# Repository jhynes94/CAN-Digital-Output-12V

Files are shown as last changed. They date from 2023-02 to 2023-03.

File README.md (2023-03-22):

# CAN-Digital-Output-12V
CAN controlled Digital Outputs providing 12V power with __ Current each.

## Items to complete
1. Detemine MOSFET to use for design (based on Current(A)/Costs constraints).
2. Design better interface board to use Arduino Nano Programmer
    1. JST Connector to Arduino Development Board
    2. 2.54mm Connector with standard interface board
    3. Consider adding UART connector as well.
3. Determine modes needed for device
    1. CAN ID changing?
    2. CAN Mode changing?
    3. How this should be modified? (DIP swich or via SW)

## Development Setup

Programming the ATTiny is a bit difficult. Setup can be completed using the following tutorial:
https://youtu.be/AL9vK_xMt4E

The library used for SPI enabled CAN device:
https://github.com/autowp/arduino-mcp2515

PEAK CAN usb device is used for interfacing and development. The software to run this is called <b>pcanview<b>

## Far Future items

Future Tutorial for programming an alternative way:
https://www.youtube.com/watch?v=ra7bT74EGUs

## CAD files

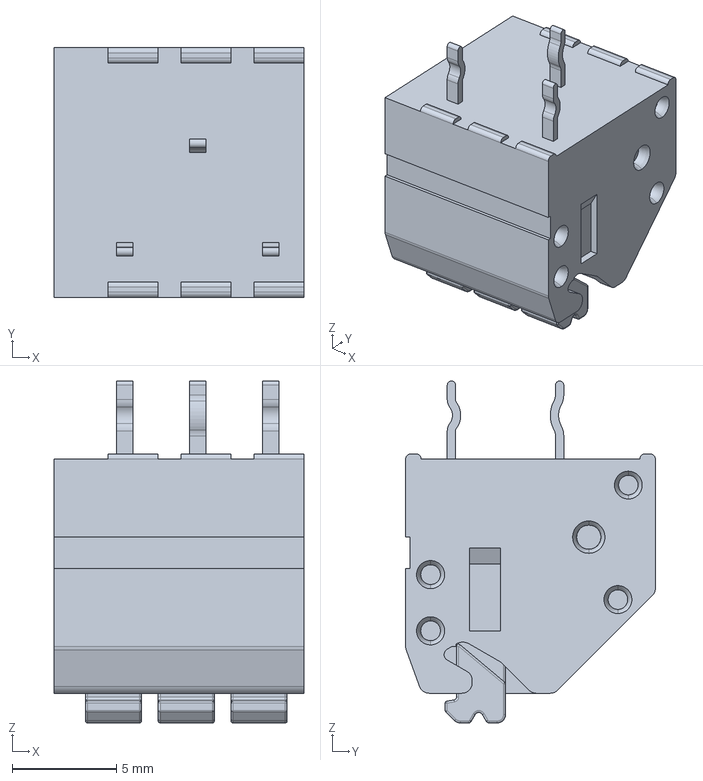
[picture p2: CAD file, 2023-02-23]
KICAD/Custom Components/1-2834011-3/1-2834011-3.step
12.0 x 12.0 x 16.4 mm

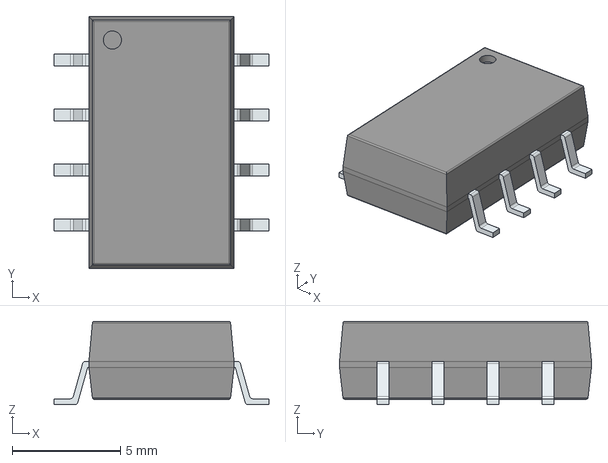
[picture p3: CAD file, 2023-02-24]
KICAD/Custom Components/219-4MSTR/219-4MSTR.stp
9.91 x 11.6 x 3.85 mm
PinsArrayLR

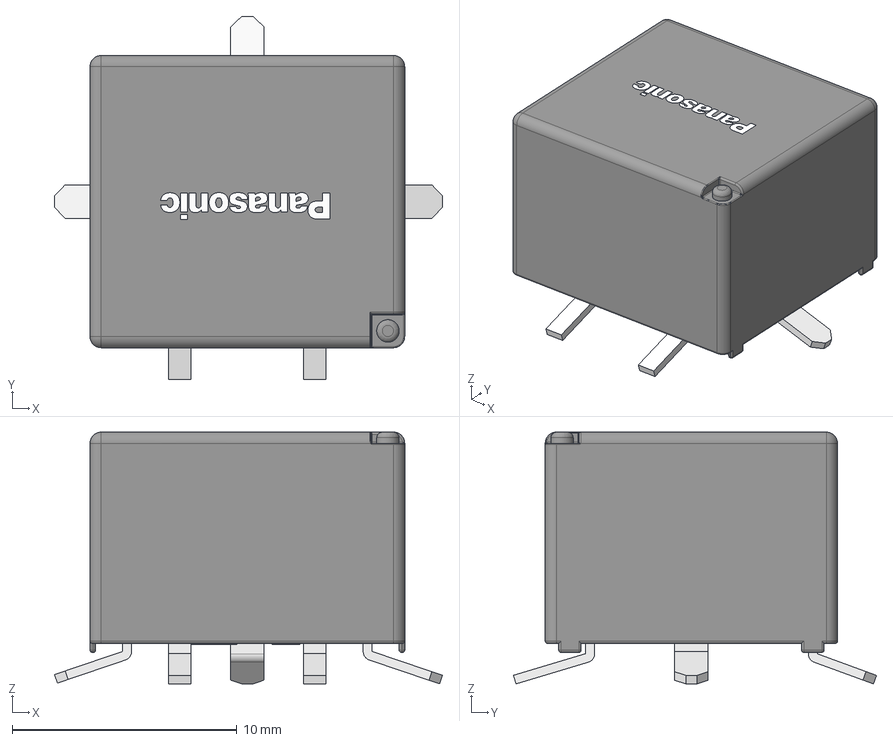
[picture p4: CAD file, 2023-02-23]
KICAD/Custom Components/eec.models/Panasonic_-_CP1SA-12V-X.step
17.3 x 16.2 x 11.2 mm
Relay
Leads
ring
Japan
Panasonic

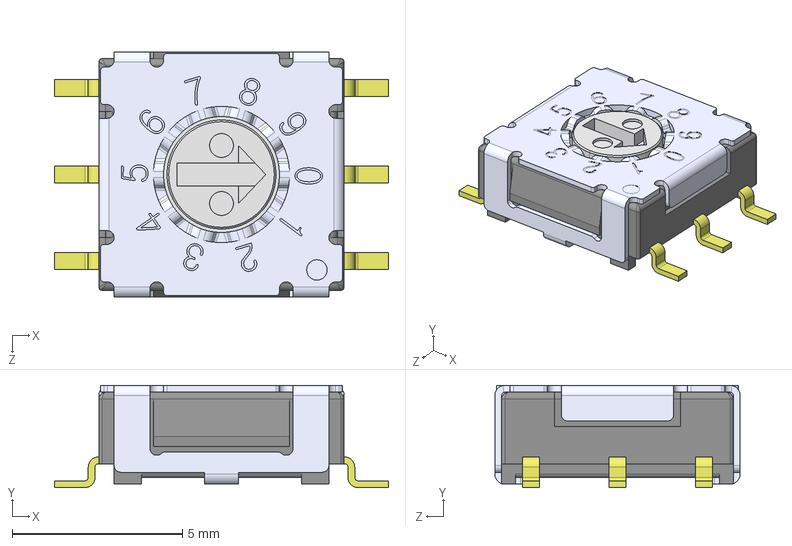
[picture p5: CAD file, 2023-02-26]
KICAD/Custom Components/RDS-10S-7229-A-SMT/CUI_DEVICES_RDS-10S-7229-A-SMT.step
9.80 x 3.00 x 7.20 mm
RDS-7229-SMT housing
RDS-7229_10_face plate
RDS-7229_flat arrow(10S)

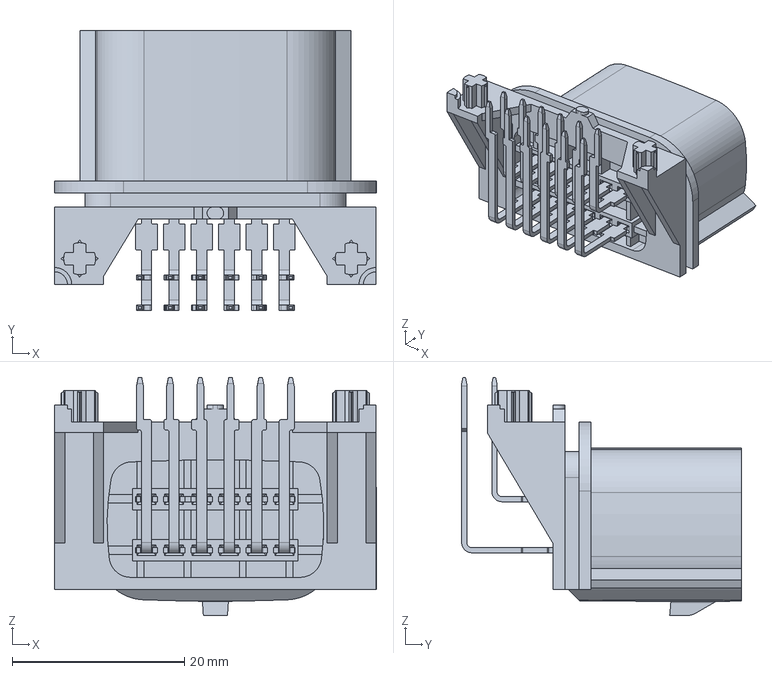
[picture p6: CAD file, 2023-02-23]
KICAD/Custom Components/0367831201/36783-1201.stp
37.4 x 32.5 x 27.6 mm

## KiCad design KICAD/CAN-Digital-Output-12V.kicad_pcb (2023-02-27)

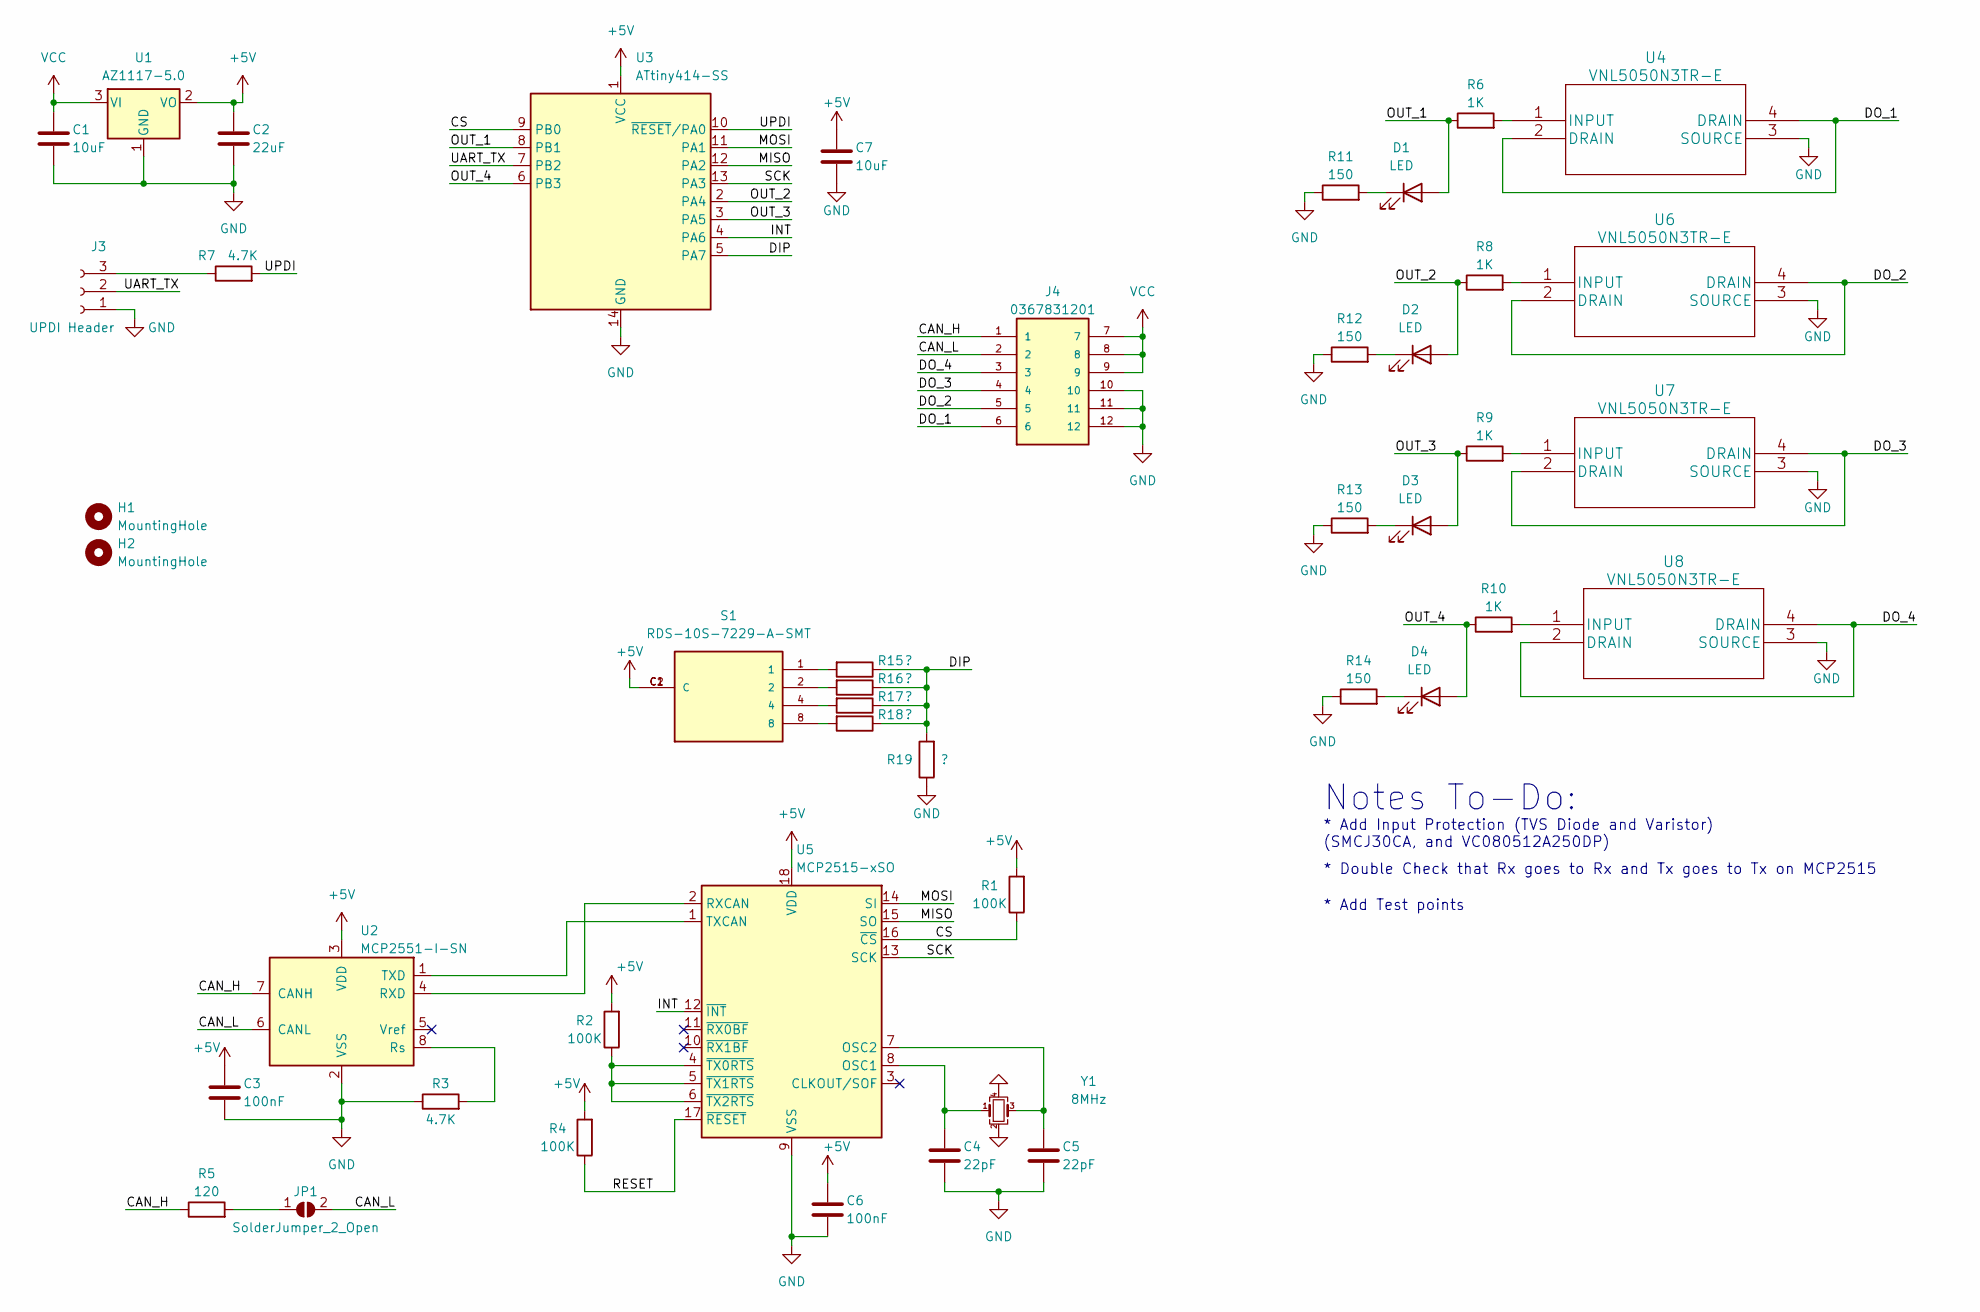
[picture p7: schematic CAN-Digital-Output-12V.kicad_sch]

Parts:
C1, C7: 10uF; C_0805_2012Metric_Pad1.18x1.45mm_HandSolder; Manufacturer PN CL21A106KOQNNNE; Digi-Key PN 1276-1096-2-ND
C2: 22uF; C_0805_2012Metric_Pad1.18x1.45mm_HandSolder; Manufacturer PN CL21A226MOCLRNC; Digi-Key PN 1276-6780-1-ND
C3, C6: 100nF; C_0603_1608Metric_Pad1.08x0.95mm_HandSolder; Manufacturer PN CL10B104KB8NNNC; Digi-Key PN 1276-1000-1-ND
C4, C5: 22pF; C_0603_1608Metric_Pad1.08x0.95mm_HandSolder; Manufacturer PN CC0603JRNPO9BN220; Digi-Key PN 311-1062-1-ND
D1, D2, D3, D4: LED; LED_0603_1608Metric_Pad1.05x0.95mm_HandSolder; Manufacturer PN LTST-C191KGKT; Digi-Key PN 160-1446-1-ND
H1, H2: MountingHole; MountingHole_2.2mm_M2_ISO14580
J3: UPDI Header; PinHeader_1x03_P1.27mm_Vertical
J4: 0367831201; MOLEX_0367831201; PARTREV F1; Digi-Key PN WM9330-ND
JP1: SolderJumper_2_Open; SolderJumper-2_P1.3mm_Open_TrianglePad1.0x1.5mm
R1, R2, R4: 100K; R_0603_1608Metric_Pad0.98x0.95mm_HandSolder; Manufacturer PN RC0603FR-07100KL; Digi-Key PN 311-100KHRCT-ND
R3, R7: 4.7K; R_0603_1608Metric_Pad0.98x0.95mm_HandSolder; Manufacturer PN RC0402JR-074K7L; Digi-Key PN 311-4.7KJRCT-ND
R5: 120; R_1206_3216Metric_Pad1.30x1.75mm_HandSolder; Manufacturer PN AC1206FR-07120RL; Digi-Key PN YAG3810CT-ND
R6, R8, R9, R10: 1K; R_0603_1608Metric_Pad0.98x0.95mm_HandSolder; Manufacturer PN RC0603FR-071KL; Digi-Key PN 311-1.00KHRCT-ND
R11, R12, R13, R14: 150; R_0603_1608Metric_Pad0.98x0.95mm_HandSolder; Manufacturer PN RC0603FR-07150RL; Digi-Key PN 311-150HRCT-ND
R15, R16, R17, R18, R19: ?; R_0603_1608Metric_Pad0.98x0.95mm_HandSolder
S1: RDS-10S-7229-A-SMT; SW_RDS-10S-7229-A-SMT; PARTREV 1.0; Digi-Key PN 2223-RDS-10S-7229-A-SMT-ND
U1: AZ1117-5.0; SOT-223-3_TabPin2; Manufacturer PN AZ1117IH-5.0TRG1; Digi-Key PN AZ1117IH-5.0TRG1DICT-ND
U2: MCP2551-I-SN; SOIC-8_3.9x4.9mm_P1.27mm; Manufacturer PN MCP2551-I/SN; Digi-Key PN MCP2551-I/SN-ND
U3: ATtiny414-SS; SOIC-14_3.9x8.7mm_P1.27mm; Manufacturer PN ATTINY414-SSNR; Digi-Key PN ATTINY414-SSNRCT-ND
U4, U6, U7, U8: VNL5050N3TR-E; SOT-223; Manufacturer PN VNL5050N3TR-E; Digi-Key PN 497-11709-1-ND
U5: MCP2515-xSO; SOIC-18W_7.5x11.6mm_P1.27mm; Manufacturer PN MCP2515-I/SO; Digi-Key PN MCP2515-I/SO-ND
Y1: 8MHz; Crystal_SMD_3225-4Pin_3.2x2.5mm_HandSoldering; Manufacturer PN ECS-80-8-33-JEN-TR3; Digi-Key PN 50-ECS-80-8-33-JEN-TR3CT-ND

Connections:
+5V: C2.1, C3.1, C6.1, C7.1, R1.2, R2.2, R4.2, S1.C1 (C), S1.C2 (C), U1.2 (VO), U2.3 (VDD), U3.1 (VCC), U5.18 (VDD)
/CAN_H: J4.1, R5.1, U2.7 (CANH)
/CAN_L: J4.2, JP1.2 (B), U2.6 (CANL)
/CS: R1.1, U3.9 (PB0), U5.16 (~CS)
/DIP: R15.1, R16.1, R17.1, R18.1, R19.2, U3.5 (PA7)
/DO_1: J4.6, U4.2 (DRAIN), U4.4 (DRAIN)
/DO_2: J4.5, U6.2 (DRAIN), U6.4 (DRAIN)
/DO_3: J4.4, U7.2 (DRAIN), U7.4 (DRAIN)
/DO_4: J4.3, U8.2 (DRAIN), U8.4 (DRAIN)
/INT: U3.4 (PA6), U5.12 (~INT)
/MISO: U3.12 (PA2), U5.15 (SO)
/MOSI: U3.11 (PA1), U5.14 (SI)
/OUT_1: D1.2 (A), R6.1, U3.8 (PB1)
/OUT_2: D2.2 (A), R8.1, U3.2 (PA4)
/OUT_3: D3.2 (A), R9.1, U3.3 (PA5)
/OUT_4: D4.2 (A), R10.1, U3.6 (PB3)
/RESET: R4.1, U5.17 (~RESET)
/SCK: U3.13 (PA3), U5.13 (SCK)
/UART_TX: J3.2, U3.7 (PB2)
/UPDI: R7.2, U3.10 (~RESET/PA0)
GND: C1.2, C2.2, C3.2, C4.2, C5.2, C6.2, C7.2, J3.1, J4.10, J4.11, J4.12, R3.1, R11.1, R12.1, R13.1, R14.1, R19.1, U1.1 (GND), U2.2 (VSS), U3.14 (GND), U4.3 (SOURCE), U5.9 (VSS), U6.3 (SOURCE), U7.3 (SOURCE), U8.3 (SOURCE), Y1.2, Y1.4
unnamed: C4.1, U5.8 (OSC1), Y1.1
unnamed: C5.1, U5.7 (OSC2), Y1.3
unnamed: D1.1 (K), R11.2
unnamed: D2.1 (K), R12.2
unnamed: D3.1 (K), R13.2
unnamed: D4.1 (K), R14.2
unnamed: J3.3, R7.1
unnamed: JP1.1 (A), R5.2
unnamed: R2.1, U5.4 (~TX0RTS), U5.5 (~TX1RTS), U5.6 (~TX2RTS)
unnamed: R3.2, U2.8 (Rs)
unnamed: R6.2, U4.1 (INPUT)
unnamed: R8.2, U6.1 (INPUT)
unnamed: R9.2, U7.1 (INPUT)
unnamed: R10.2, U8.1 (INPUT)
unnamed: R15.2, S1.1
unnamed: R16.2, S1.2
unnamed: R17.2, S1.4
unnamed: R18.2, S1.8
unnamed: U2.1 (TXD), U5.1 (TXCAN)
unnamed: U2.4 (RXD), U5.2 (RXCAN)
VCC: C1.1, J4.7, J4.8, J4.9, U1.3 (VI)

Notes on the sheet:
* Add Input Protection (TVS Diode and Varistor) (SMCJ30CA, and VC080512A250DP)
* Double Check that Rx goes to Rx and Tx goes to Tx on MCP2515
Notes To-Do:
* Add Test points

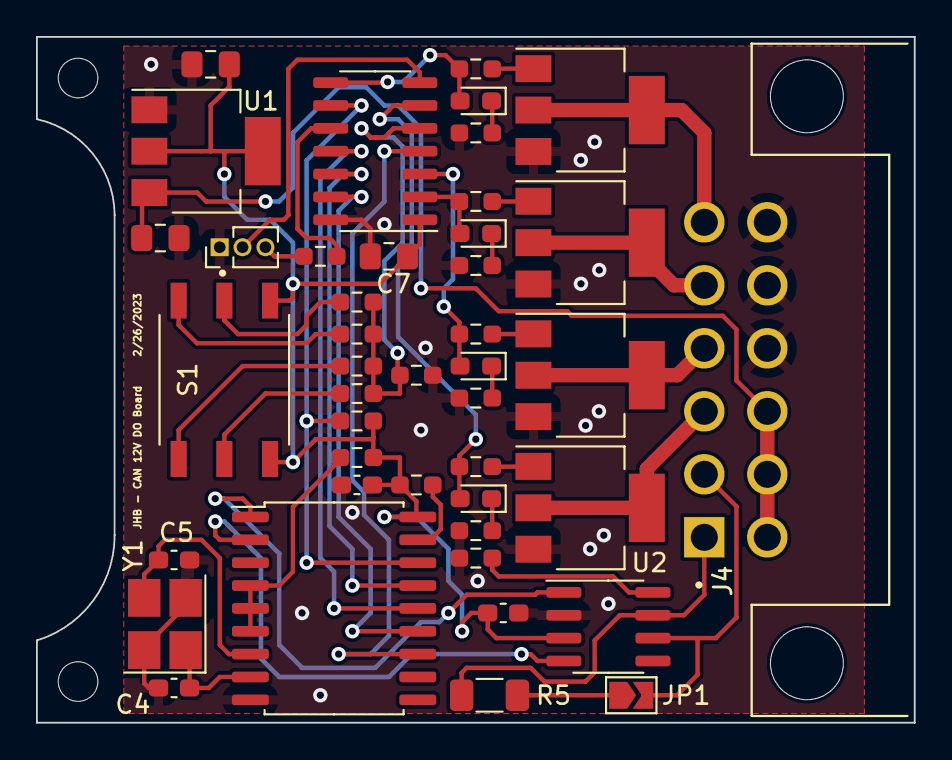
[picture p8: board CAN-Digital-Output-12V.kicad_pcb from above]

Board: 2 copper layers, 48.8 x 38.1 mm, 45 parts (0 on the bottom side), 42 nets.

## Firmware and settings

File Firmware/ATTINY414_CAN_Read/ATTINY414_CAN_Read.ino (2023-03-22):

#include <SPI.h>
#include <mcp2515.h>

#define OUT_1 6
#define OUT_2 0
#define OUT_3 1
#define OUT_4 4

bool blink_Out_1 = false
bool blink_Out_2 = false
bool blink_Out_3 = false
bool blink_Out_4 = false

struct can_frame canMsg;
MCP2515 mcp2515(7);

unsigned int device_CAN_ID = 1;

void setup() {
  
  mcp2515.reset();
  mcp2515.setBitrate(CAN_125KBPS, MCP_8MHZ);
  mcp2515.setNormalMode();

  //Setup Digital Outputs
  pinMode(OUT_1, OUTPUT);
  pinMode(OUT_2, OUTPUT);
  pinMode(OUT_3, OUTPUT);
  pinMode(OUT_4, OUTPUT);
}

void loop() {

  if (mcp2515.readMessage(&canMsg) == MCP2515::ERROR_OK) {
      
    //If it is the correct CAN ID
    if(canMsg.can_id == device_CAN_ID){
      
      unsigned int mask = 0b00000010;
      if((canMsg.data[0]&mask) != 0){
        digitalWrite(OUT_1, HIGH);
      }
      else {
        digitalWrite(OUT_1, LOW);
      }
      
      /*
      //Iterates Through Data    
      for (int i = 0; i<canMsg.can_dlc; i++) {
        //canMsg.data[i],HEX);
      }
      */
    }
  }
}

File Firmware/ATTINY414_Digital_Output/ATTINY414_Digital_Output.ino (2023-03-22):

#include <SPI.h>
#include <mcp2515.h>

#define OUT_1 6
#define OUT_2 0
#define OUT_3 1
#define OUT_4 4

bool blink_Out_1 = false;
bool blink_Out_2 = false;
bool blink_Out_3 = false;
bool blink_Out_4 = false;

struct can_frame canMsg;
MCP2515 mcp2515(7);

unsigned int device_CAN_ID = 1;

unsigned long currentMillis;
unsigned long previousMillis = 0;
const unsigned long interval = 1000;
int ledState = LOW;

void setup() {
  
  mcp2515.reset();
  mcp2515.setBitrate(CAN_125KBPS, MCP_8MHZ);
  mcp2515.setNormalMode();

  //Setup Digital Outputs
  pinMode(OUT_1, OUTPUT);
  pinMode(OUT_2, OUTPUT);
  pinMode(OUT_3, OUTPUT);
  pinMode(OUT_4, OUTPUT);
}

void loop() {

  if (mcp2515.readMessage(&canMsg) == MCP2515::ERROR_OK) {
      
    //If it is the correct CAN ID
    if(canMsg.can_id == device_CAN_ID){
      
      if(canMsg.data[0] > 0){
        digitalWrite(OUT_1, HIGH);
        blink_Out_1 = false;
        if(canMsg.data[0] > 10){
          blink_Out_1 = true;
        } 
      }
      else {
        digitalWrite(OUT_1, LOW);
        blink_Out_1 = false;
      }


      if(canMsg.data[1] > 0){
        digitalWrite(OUT_2, HIGH);
        blink_Out_2 = false;
        if(canMsg.data[1] > 10){
          blink_Out_2 = true;
        }
      }
      else {
        digitalWrite(OUT_2, LOW);
        blink_Out_2 = false;
      }

      if(canMsg.data[2] > 0){
        digitalWrite(OUT_3, HIGH);
        blink_Out_3 = false;
        if(canMsg.data[2] > 10){
          blink_Out_3 = true;
        }
      }
      else {
        digitalWrite(OUT_3, LOW);
        blink_Out_3 = false;
      }
      
      if(canMsg.data[3] > 0){
        digitalWrite(OUT_4, HIGH);
        blink_Out_4 = false;
        if(canMsg.data[3] > 10){
          blink_Out_4 = true;
        }
      }
      else {
        digitalWrite(OUT_4, LOW);
        blink_Out_4 = false;
      }

      /*
      //Iterates Through Data    
      for (int i = 0; i<canMsg.can_dlc; i++) {
        //canMsg.data[i],HEX);
      }
      */
    }
  }
  currentMillis = millis();
  if (currentMillis - previousMillis >= interval) {
    // save the last time you blinked the LED
    previousMillis = currentMillis;

    // if the LED is off turn it on and vice-versa:
    if (ledState == LOW) {
      ledState = HIGH;
    } else {
      ledState = LOW;
    }

    if(blink_Out_1 == true){
      digitalWrite(OUT_1, ledState);
    }
    if(blink_Out_2 == true){
      digitalWrite(OUT_2, ledState);
    }
    if(blink_Out_3 == true){
      digitalWrite(OUT_3, ledState);
    }
    if(blink_Out_4 == true){
      digitalWrite(OUT_4, ledState);
    }
  }
}

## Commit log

2023-02-23 First major commit
    [1-2834011-3.step, CAN-Digital-Output-12V.kicad_pcb, CAN-Digital-Output-12V.kicad_sch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]
2023-02-23 Design review with Jarrod
    [36783-1201.stp, CAN-Digital-Output-12V.kicad_pcb, CAN-Digital-Output-12V.kicad_sch]
2023-02-24 Third Design Review
    [219-4MSTR.stp, CAN-Digital-Output-12V.kicad_pcb, CAN-Digital-Output-12V.kicad_sch]
2023-02-24 V1 Schematic and Placement Design complete
    [CAN-Digital-Output-12V.kicad_pcb, CAN-Digital-Output-12V.kicad_sch]
2023-02-26 Added rotary switch
    [CAN-Digital-Output-12V.kicad_pcb, CAN-Digital-Output-12V.kicad_sch, CUI_DEVICES_RDS-10S-7229-A-SMT.step]
2023-02-27 Sent to Fab
    [CAN-Digital-Output-12V-B_Cu.gbl, CAN-Digital-Output-12V-B_Mask.gbs, CAN-Digital-Output-12V-B_Paste.gbp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]
2023-03-22 V1 Software is fully functional
    [CAN-Digital-Output-12V.kicad_sch]
